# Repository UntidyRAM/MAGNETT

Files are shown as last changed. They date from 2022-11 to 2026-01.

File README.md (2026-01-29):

# MAGNETT 🧲
<b>M</b>agnetometer<br/>
<b>A</b>ugmentation<br/>
<b>G</b>adget for<br/>
<b>N</b>etwork<br/>
<b>E</b>nabled<br/>
<b>T</b>elemetry<br/>
<b>T</b>ransmission<br/>
<br/>

<p align="justify">
MAGNETT is a proof of concept device (or gadget) that allows one to retrieve measurements taken from a G-856AX (manufactured by Geometrics, Inc) over a WiFi connection. It has the ability to save a GPS position for each measurement taken by the G-856AX. It also displays the retrieved data in a table and graph on the web server.  
</p>

<p align="justify">
Our device makes use of an ESP32 and a GPS (amongst other less notable components) to realise the features mentioned above. 
</p>

This project forms part of our fourth year investigating course, for electrical engineering, at the University of the Witwatersrand, Johannesburg. 

By Huan Lei & Nicholas Warrener 

# Images
## Device
<p align="justify">
A top view image of our device can be seen below. Our device uses a 5000mAh LiPo battery. 
</p>
<br/>

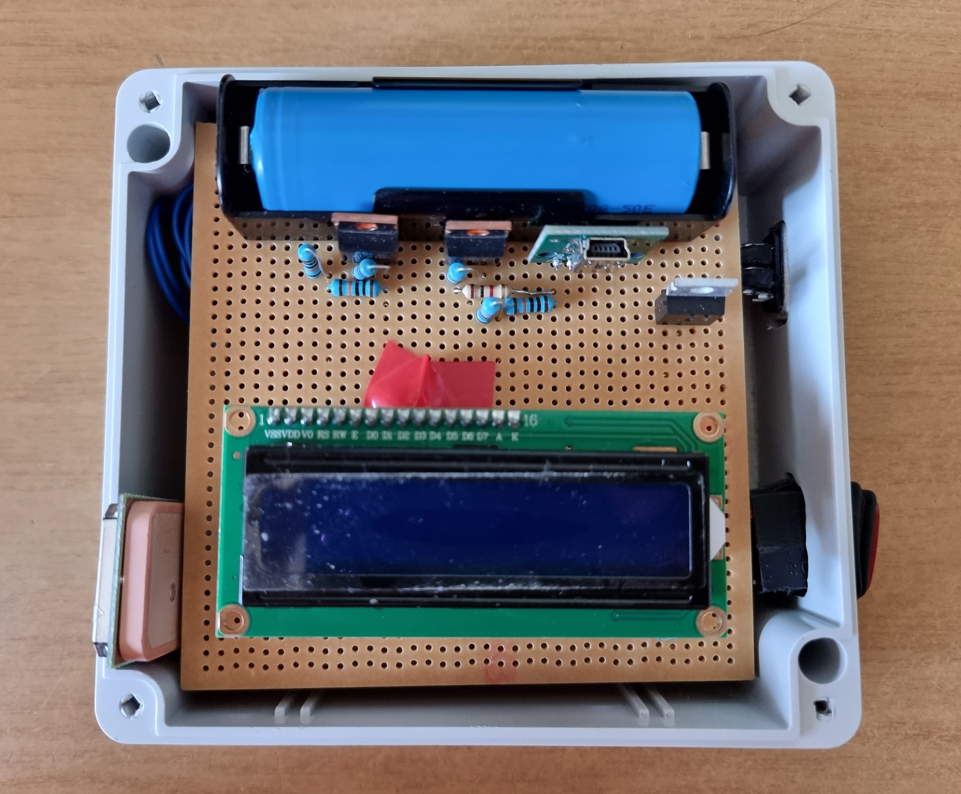
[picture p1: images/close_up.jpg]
An image showing the top view of our device. A battery, USB port, two MOSFETs, a display, and the GPS antenna can be seen. Top view of MAGNETT.


<p align="justify">
Our device and it's custom connector can be seen inside of the carrying case for a G-856AX. 
</p>
<br/>

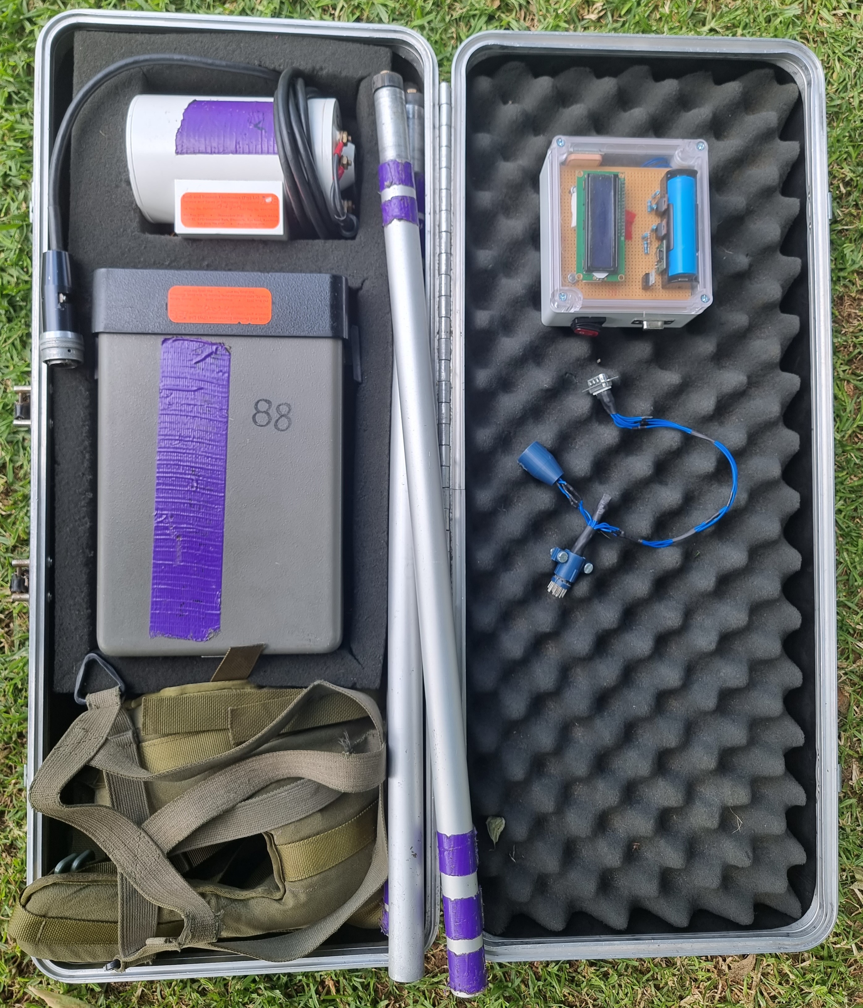
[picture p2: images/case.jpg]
An image showing our device sitting inside the carrying case for a Geometrics G-856AX proton precession magnetometer. The magnetometer's console and sensor can be seen as well as the poles used to hold up the sensor. MAGNETT with a G-856AX.


## Website 
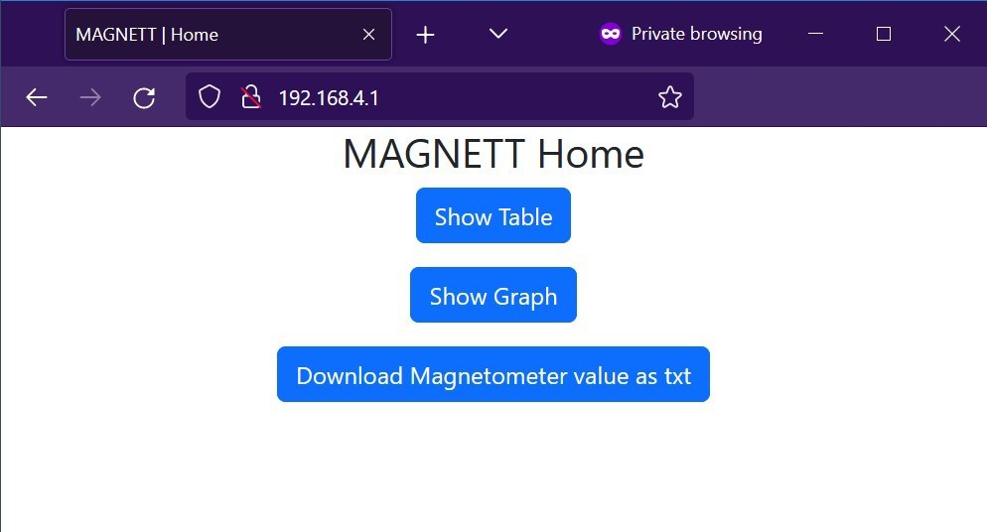
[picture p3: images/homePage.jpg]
Our device's homepage displaying three buttons: Table, Graph and Download data. MAGNETT home page.


<p align="justify">
The data in the next three images was taken from a G-856AX. The GPS data corresponding to each magnetic field reading was taken using MAGNETT's built-in NEO-6M GPS. The GPS data has been censored for privacy reasons. 
</p>
<br/>

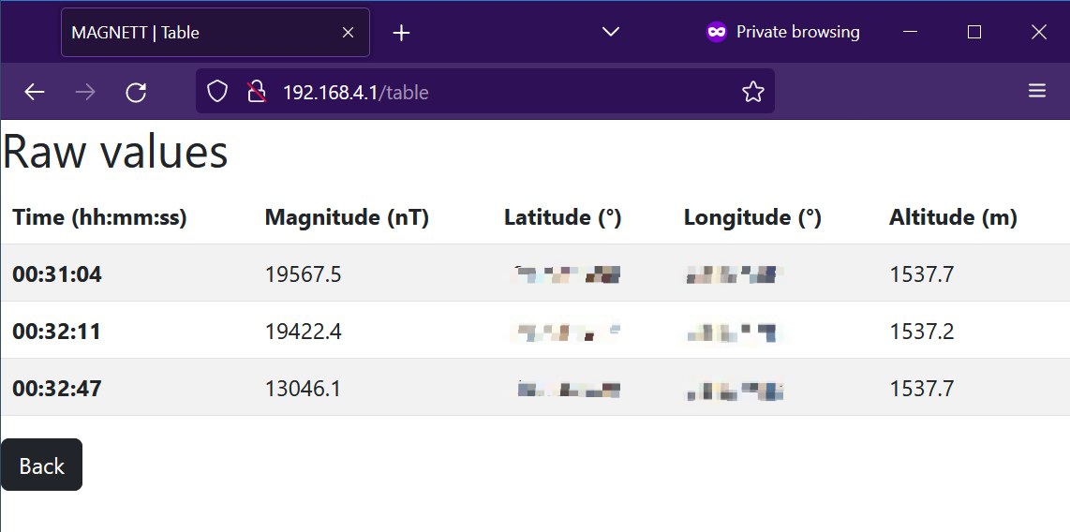
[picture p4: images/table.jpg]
A webpage displaying a table with three rows of data. MAGNETT table page.


<br/>

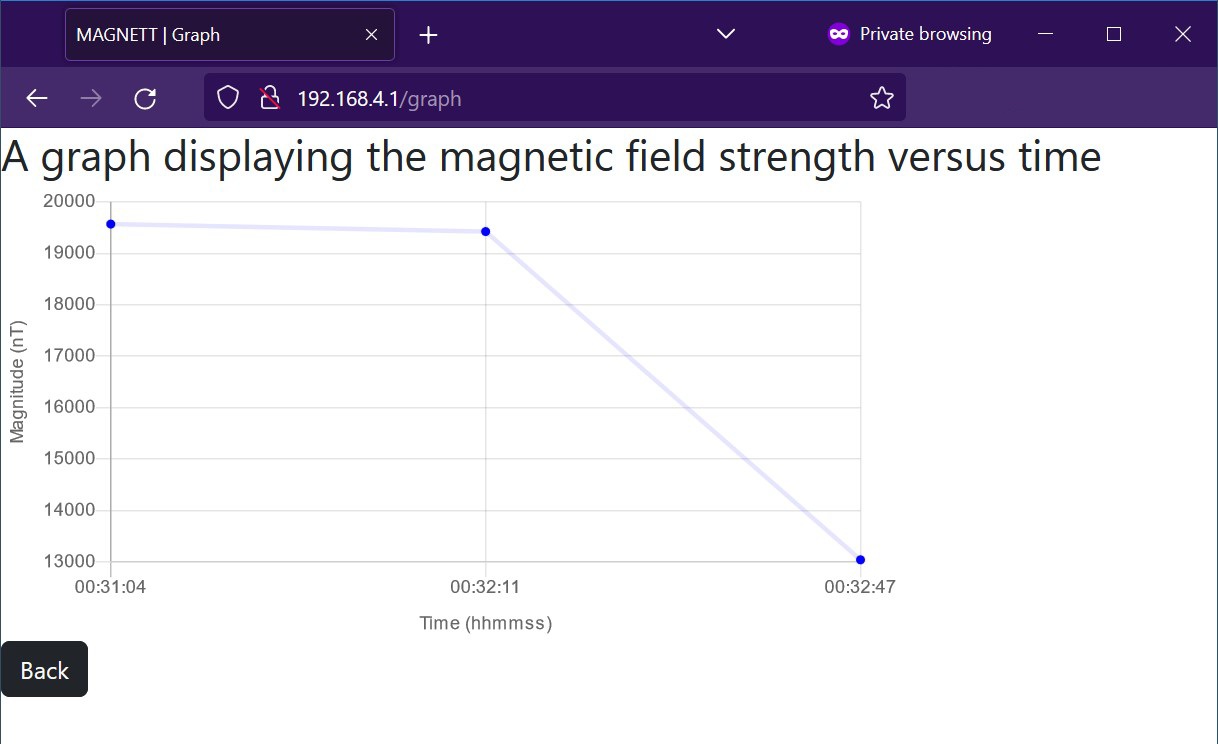
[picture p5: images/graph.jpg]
A line graph displaying a plot of the magnetic field strength versus time. MAGNETT graph page.


<br/>

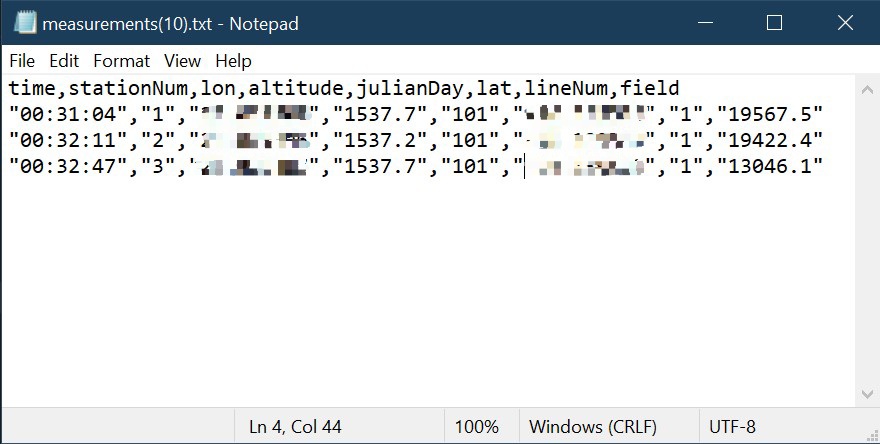
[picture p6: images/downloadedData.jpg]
A screenshot of a text document containing data downloaded from our device. MAGNETT downloaded data.


# Dependencies 
## LCD
<p align="justify">
Our project uses a generic 1609 LCD with an I2C 'backpack' to reduce the number of wires needed for communication. We used the 
<a href="https://github.com/dhylands/python_lcd">python_LCD</a> library to configure the LCD and display text. Specifically, <code>machine_i2c_lcd.py</code> and <code>lcd_api.py</code> are used from this library.
</p>

## GPS
<p align="justify">
We used the <code>as_GPS.py</code> driver from the <a href="https://github.com/peterhinch/micropython-async">micropython-async</a> library to asynchronously parse the NMEA sentences from the GPS. Just make sure to use V2 and not V3 as the newer version contains functions not supported by the version of micropython-async running on TinyWeb.
</p>

## Webserver
[Bootstrap](https://github.com/twbs/bootstrap/tree/v5.2.2/site/content/docs/5.2)- We used the latest release at the time of writing (V5.2.2) <br/>
[Chart.js](https://www.chartjs.org/docs/2.9.4/) - We used an older version (V2.9.4) of this library because we ran into issues running the latest version<br/>
[TinyWeb](https://github.com/belyalov/tinyweb) - The latest release (V1.3.5) is from 2020 which means we had to use an older version of the as_GPS library.

# Acknowledgements
<p align="justify">
We would like to thank Prof K. Nixon for supervising our project and providing us with valuable feedback at the review meetings. We would also like to thank Prof S. Webb of the Geoscience Department for providing us with the necessary hardware as well as giving us valuable feedback and information which helped us contextualize the design. 
</p>

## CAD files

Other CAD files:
models/female/Female Adapter.ipt
models/female/Inner Part of Female.ipt
models/male/Inner Part of Male.ipt
models/male/Male Adapter.ipt

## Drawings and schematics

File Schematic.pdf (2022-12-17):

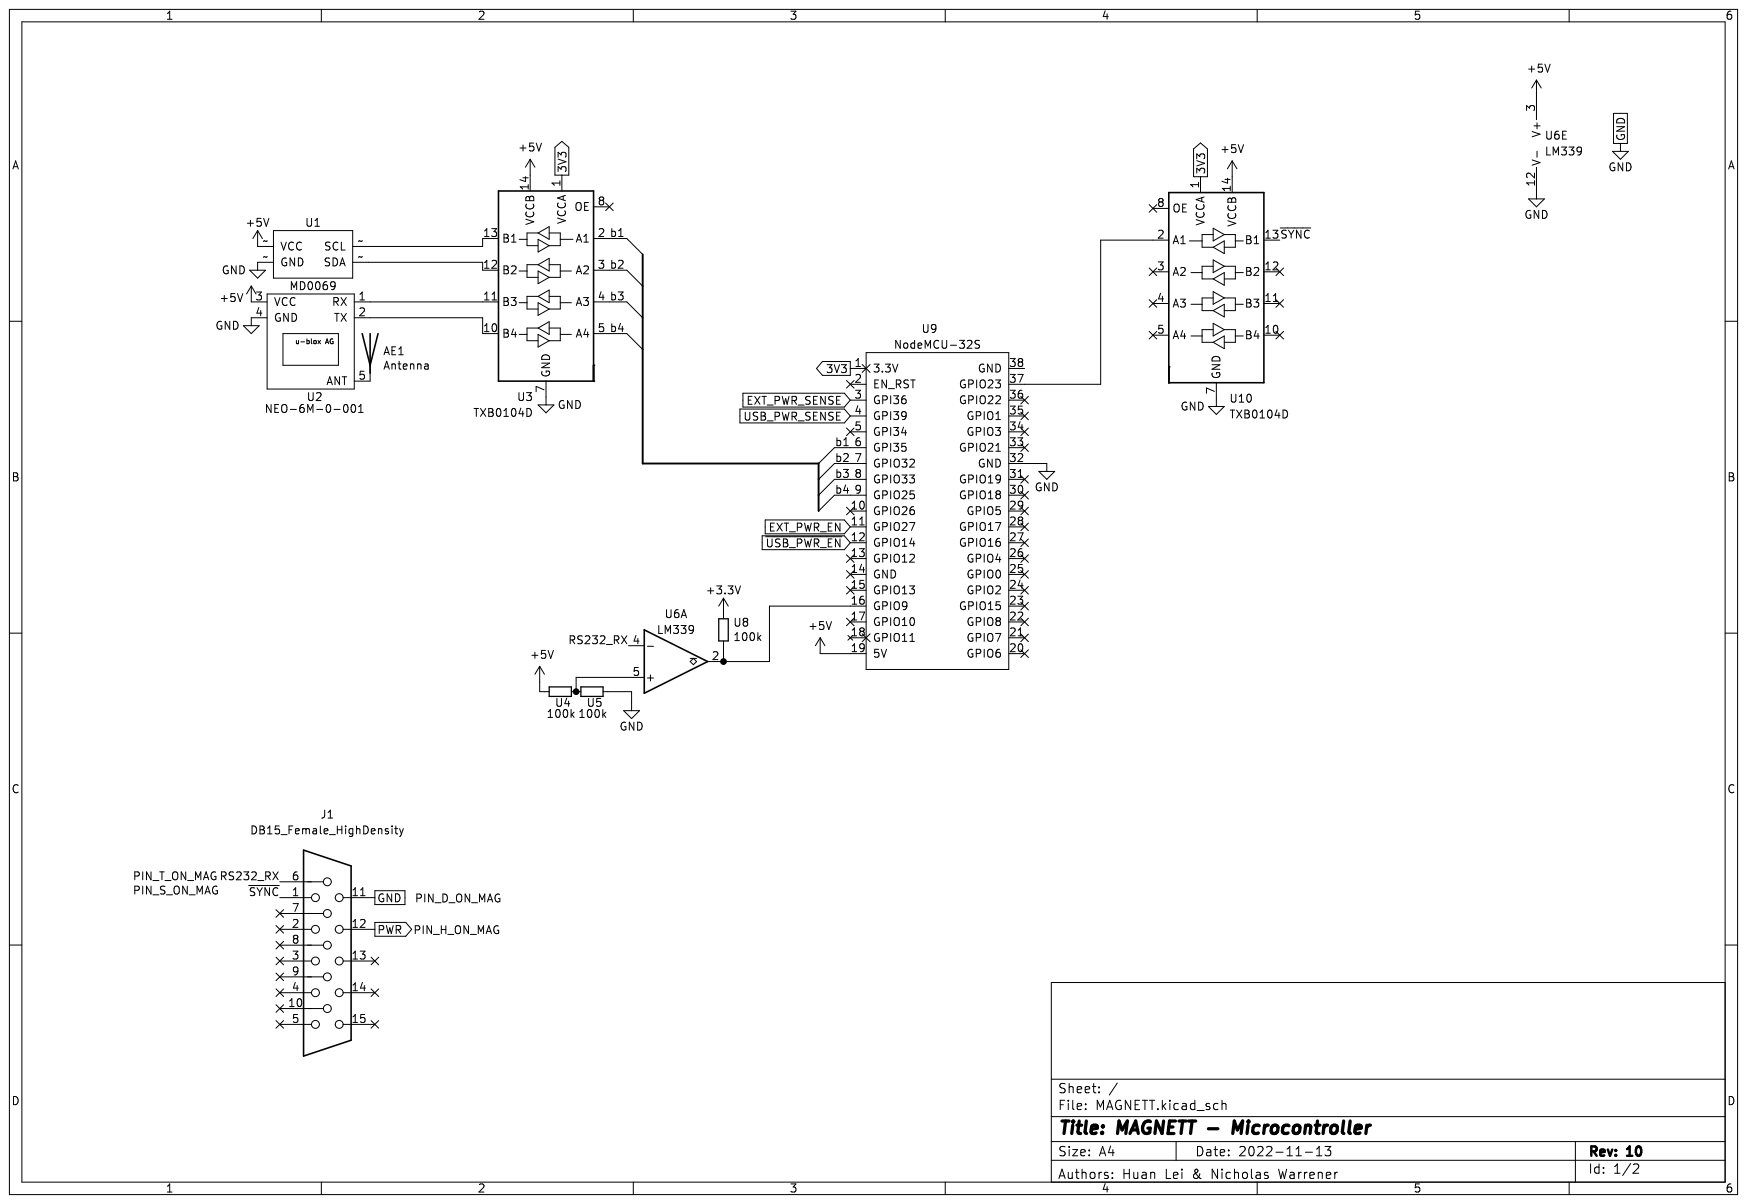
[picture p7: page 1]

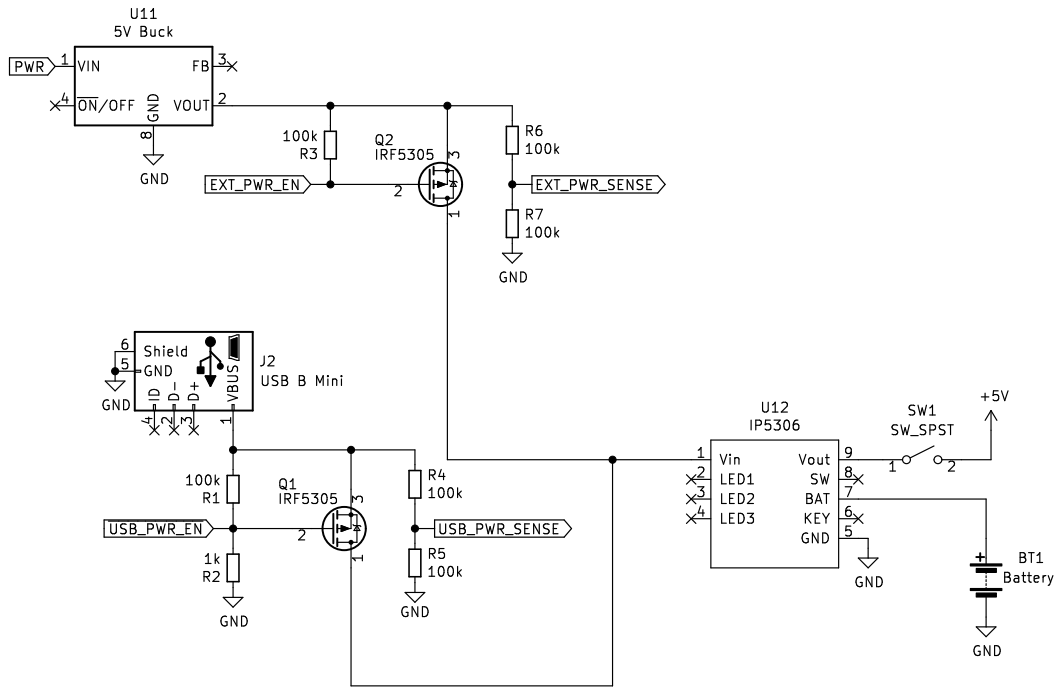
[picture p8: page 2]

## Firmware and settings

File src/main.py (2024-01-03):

# Copyright (c) 2022 Huan Lei and Nicholas Warrener 
# Released under the MIT License (MIT) - see LICENSE file

import tinyweb
import network
import time
import json
import machine
import uasyncio as asyncio

from machine import Pin, I2C, UART
from lcd_api import LcdApi
from machine_i2c_lcd import I2cLcd
from time import sleep
from AS_GPS import AS_GPS
from math import floor, modf

# LCD
I2C_ADDR = 0x27
totalRows = 2
totalColumns = 16

i2c = I2C(scl=Pin(21), sda=Pin(22), freq=10000)
lcd_obj = I2cLcd(i2c, I2C_ADDR, totalRows, totalColumns)
lcd_obj.putstr("Waiting for GPS")

# Control the MOSFETs for power selection.
# Be careful not to turn both of them on if you have two supplies connected
ext_pwr_status = Pin(19, Pin.IN)
ext_pwr_ctrl = Pin(18, Pin.OUT)
ext_pwr_ctrl.on() # Turn off external power.

usb_pwr_stats = Pin(4, Pin.IN)
usb_pwr_ctrl = Pin(5, Pin.OUT)
usb_pwr_ctrl.off() # Turn on USB power for charging.

# Globals
rs232DictArr = []
gpsDictArr = []

# Magnetometer serial
magSerial = UART(1, 9600, bits=7, parity=None, stop=2, rx=16, tx=10)

# We implement a falling edge detector in software instead of using a hardware interrupt for two reasons.
# Firstly, the time savings between asynchronously polling the pin and using a hardware interrupt is negligible.
# Secondly, introducing an interrupt into asynchronous code increases the complexity of the code.
magSyncPin = Pin(23, mode=Pin.IN)
pin_state = magSyncPin.value()
last_pin_state = pin_state

# GPS serial
gpsSerial = UART(2, baudrate=9600, bits=8, parity=None, stop=1, tx=25, rx=33) 
sreader = asyncio.StreamReader(gpsSerial)
gps = AS_GPS(sreader)
isGPSReady = False

# Create web server application
app = tinyweb.webserver()

async def gpsRecv():
    while True:
        global isGPSReady
        if isGPSReady == False:
            await gps.data_received(position=True, altitude=True)
            lcd_obj.clear()
            lcd_obj.putstr("GPS ready\nSurvey can begin")
            isGPSReady = True
            await asyncio.sleep_ms(100)
        else:
            while True:
                pin_state = magSyncPin.value()
                if not pin_state and last_pin_state:
                    await gps.data_received(position=True, altitude=True)
                    lcd_obj.clear()
                    lcd_obj.putstr("lat:" + gps.latitude_string(coord_format=4) + "\nlon:" + gps.longitude_string(coord_format=4))
                    global gpsDictArr
                    gpsDictArr.append({"lat": gps.latitude_string(coord_format=4), "lon": gps.longitude_string(coord_format=4), "altitude": str(gps.altitude)})
                    await asyncio.sleep_ms(100)

                last_pin_state = pin_state
                await asyncio.sleep_ms(10)

async def rs232Recv(uart):
    reader = asyncio.StreamReader(uart)
    while True:
        message = await reader.readline()
        await asyncio.sleep_ms(100)
        message = message.decode("ASCII")

        # Using the info in the manual, we can split up the output from the magnetometer.
        lineNum = message[1:4]
        julianDay = message[5:8]
        time = message[9:15]
        stationNum = message[16:20]
        field = message[21:27]

        # Format the time so it changes from hhmmss to hh:mm:ss.
        time = str(time[:2]) + ":" + str(time[2:4]) + ":" + str(time[4:6])

        # EDIT: The following commented out code is not correcting a bug! The '?' is intentional and indicates that the measurement was made in a high
        #       gradient.
        # Replace any question marks with zeros. This happens because of a bug in the G-856AX's serial code.
        # if '?' in field:
        #    field = field.replace('?', '0')

        # Format the field reading to have its decimal point. A raw value is 517643 which is formatted to 51764.3
        field = field[:len(field) - 1] + "." + field[len(field) - 1:]
        rs232DictArr.append({"lineNum": str(lineNum), "julianDay": str(julianDay), "time": str(time), "stationNum": str(stationNum), "field": str(field)})

        await asyncio.sleep_ms(100)


# Landing page
@app.route('/')
async def index(request, response):
    global rs232DictArr
    global gpsDictArr
    
    # Start HTTP response with content-type text/html
    await response.start_html()

    vals = ""
    # This if statement should just check that each magnetometer reading has a corresponding gps reading.
    if len(rs232DictArr) != 0 and len(gpsDictArr) != 0 and len(rs232DictArr) == len(gpsDictArr):
        #vals = "lineNum, julianDay, time, stationNum, field, lat, lon, altitude\b"
        for x in range(len(rs232DictArr)):
            rs232DictArr[x].update(gpsDictArr[x])

        vals = json.dumps(rs232DictArr)
    else:
        # Our device is just being used to pull readings from the magnetometer. It wasn't used to save GPS values for each reading.
        if len(rs232DictArr) != 0 and len(gpsDictArr) == 0:
            #vals = "lineNum, julianDay, time, stationNum, field\n"
            for i in range(len(rs232DictArr)):
                vals += json.dumps(rs232DictArr[i]) 

    strHtml = """<!DOCTYPE html>
    <html>
    <head>
         <title>MAGNETT | Home</title>
        <meta name="viewport" content="width=device-width, initial-scale=1">
        <link href="/css" rel="stylesheet">
        <style>
            html {
                font-family: Arial;
                display: inline-block;
                margin: 0px auto;
                text-align: center;
            }

            .button {
                background-color: #000000;
                border: none;
                color: white;
                padding: 16px 40px;
                text-align: center;
                text-decoration: none;
                display: inline-block;
                font-size: 16px;
                margin: 4px 2px;
                cursor: pointer;
                border-radius: 25px;
            }
        </style>
    </head>

    <script>
    function download()
    {
        const json3 = {"count": """+str(len(rs232DictArr))+""", "items":""" + str(vals) + """}
        const items = json3.items
        const replacer = (key, value) => value === null ? '' : value // specify how you want to handle null values here
        const header = Object.keys(items[0])
        const csv = [
            header.join(','), // header row first
            ...items.map(row => header.map(fieldName => JSON.stringify(row[fieldName], replacer)).join(','))
        ].join("\\r\\n")

        var link = document.createElement('a');
        link.setAttribute('href', 'data:text;charset=utf-8,' + encodeURIComponent(csv));
        link.setAttribute('download', 'measurements.txt');
        link.style.visibility = 'hidden';
        document.body.appendChild(link);
        link.click();
        document.body.removeChild(link);
    }
    </script>

    <body>
        <h2>MAGNETT Home</h2>
        <p>
            <a href=\"table\"><button class="btn btn-primary">Show Table</button></a>
        </p>
        <p>
            <a href=\"graph\"><button class="btn btn-primary">Show Graph</button></a>
        </p>
        <p>
        
        <button class="btn btn-primary" onclick="download()">Download Magnetometer value as txt</button> 
        <a id="readings" style="display:none"></a>

        </p>
    </body>
    </html>
    """

    # Send actual HTML page
    await response.send(strHtml)

@app.route('/about')
async def index(request, response):
    # Start HTTP response with content-type text/html
    await response.start_html()

    strHtml = """
    <!DOCTYPE html>
    <html>
    <head>
         <title>MAGNETT | About</title>
        <meta name="viewport" content="width=device-width, initial-scale=1">
        <link href="/css" rel="stylesheet">
    </head>

    <body>
        <h2>MAGNETT About</h2>
        <p>
            This device was made for the Geoscience Department by Huan Lei and Nicholas Warrener for their final year investigation project. The code and design files can be found on GitHub by searching for the 'MAGNETT' repo maintained by Ray-R4y and UntidyRAM.
        </p>
    </body>
    </html>
    """
    
    # Send actual HTML page
    await response.send(strHtml)

@app.route('/js')
async def getChartLib(req, res):
    await res.send_file('/Chart.js')

@app.route('/css')
async def getChartLib(req, res):
    await res.send_file('/bootstrap.min.css')

#this is  where the chart.js and the new page will be using the /table with button above
@app.route('/table')
async def table(request, response):
    # Start HTTP response with content-type text/html
    await response.start_html()

    if len(gpsDictArr) != 0:
        await response.send('<!DOCTYPE html><html><head><title>MAGNETT | Table</title><link href="/css" rel="stylesheet"></head><body><h1>Raw values</h1>'
                            '<table class="table table-striped">'
                            '<thead>'
                                '<tr>'
                                    '<th scope="col">Time (hh:mm:ss)</th>'
                                    '<th scope="col">Magnitude (nT)</th>'
                                    '<th scope="col">Latitude (&deg;)</th>'
                                    '<th scope="col">Longitude (&deg;)</th>'
                                    '<th scope="col">Altitude (m)</th>'
                                    '</tr>'
                            '</thead>'
                            '<tbody>')

        # The table value here is a bit tricky, but we can pull it off from list, the format underneath here
        # so if we want the x and y value we put in change  it to format(x,y)

        cntr = 0

        for x in rs232DictArr:
            jsonData = json.dumps(x)
            data = json.loads(jsonData)

            tempJsonData = json.dumps(gpsDictArr[cntr])
            tempData = json.loads(tempJsonData)

            await response.send('<tr><th scope="row">' + data['time'] + '</th><td>' + data['field'] + '</td><td>' + tempData['lat'] + '</td><td>' + tempData['lon'] + '</td><td>' + tempData['altitude'] + '</td></tr>')
            
            cntr = cntr + 1

    else:
        await response.send('<!DOCTYPE html><html><head><title>MAGNETT | Table</title><link href="/css" rel="stylesheet"></head><body><h1>Raw values</h1>'
                            '<table class="table table-striped">'
                            '<thead>'
                                '<tr>'
                                    '<th scope="col">Time (hh:mm:ss)</th>'
                                    '<th scope="col">Magnitude (nT)</th>'
                                    '</tr>'
                            '</thead>'
                            '<tbody>')

        # The table value here is a bit tricky, but we can pull it off from list, the format underneath here
        # so if we want the x and y value we put in change  it to format(x,y)

        for x in rs232DictArr:
            jsonData = json.dumps(x)
            data = json.loads(jsonData)

            await response.send('<tr><th scope="row">' + data['time'] + '</th><td>' + data['field'] + '</td></tr>') 

    await response.send('</tbody></table>'
                        """<button type="button" class="btn btn-dark" onclick="history.go(-1)">Back</button></html>""")
    
@app.route('/graph')
async def graph(request, response):
    # Start HTTP response with content-type text/html
    await response.start_html()
  
    xValue = ""
    yValue = ""
    #try getting real values
    for x in rs232DictArr:
        jsonData = json.dumps(x)
        data = json.loads(jsonData)
        xValue = xValue + "'"+(data['time']) + "',"
        yValue = yValue + "'"+(data['field']) + "',"   
    xValue = xValue[:-1]
    yValue = yValue[:-1]
    await response.send("""
    <!DOCTYPE html>
    <html>
    <head>
        <title>MAGNETT | Graph</title>
        <link href="/css" rel="stylesheet">
    </head>
    <script type="application/javascript" src="/js"></script>

    <body>
        <h2>A graph displaying the magnetic field strength versus time</h2>
        <canvas id="FieldStrengthTimeGraph" style="width:100%;max-width:600px"></canvas>

        <script>
            let xValues = [""" + xValue +"""];
            let yValues = [""" + yValue +"""];

            new Chart("FieldStrengthTimeGraph", {
                type: "line",
                data: {
                    labels: xValues,
                    datasets: [{
                        fill: false,
                        lineTension: 0,
                        backgroundColor: "rgba(0,0,255,1.0)",
                        borderColor: "rgba(0,0,255,0.1)",
                        data: yValues
                    }]
                },
                options: {
                    legend: { display: false },
                    scales: {
                        yAxes: [{
                            scaleLabel: {
                                display: true,
                                labelString: 'Magnitude (nT)'
                            }
                        }],
                        xAxes: [{
                            scaleLabel: {
                                display: true,
                                labelString: 'Time (hhmmss)'
                            }
                        }],
                    }
                }
            });
        </script>
        <button type="button" class="btn btn-dark" onclick="history.go(-1)">
            Back
        </button>
    </body>
    </html>""")
    
          
async def main():
    sta_if = network.WLAN(network.AP_IF)
    sta_if.active(True)
    sta_if.config(essid='MAGNETT', password='123456789')

    while sta_if.active() == False:
        pass

    # Loop_forever=True would turn this function into a blocking function which would stop
    # our code below it from running.
    app.run(host='0.0.0.0', port=80, loop_forever=False)

    loop = asyncio.get_event_loop()
    loop.create_task(rs232Recv(magSerial))
    loop.create_task(gpsRecv())

loop = asyncio.get_event_loop()
loop.create_task(main())
loop.run_forever()

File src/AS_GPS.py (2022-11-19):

# as_GPS.py Asynchronous device driver for GPS devices using a UART.
# Sentence parsing based on MicropyGPS by Michael Calvin McCoy
# https://github.com/inmcm/micropyGPS
# http://www.gpsinformation.org/dale/nmea.htm
# Docstrings removed because of question marks over their use in resource
# constrained systems e.g. https://github.com/micropython/micropython/pull/3748

# Copyright (c) 2018-2020 Peter Hinch
# Released under the MIT License (MIT) - see LICENSE file

# astests.py runs under CPython but not MicroPython because mktime is missing
# from Unix build of utime

try:
    import uasyncio as asyncio
except ImportError:
    import asyncio

try:
    from micropython import const
except ImportError:
    const = lambda x : x

from math import modf

# Float conversion tolerant of empty field
# gfloat = lambda x : float(x) if x else 0.0

# Angle formats
DD = const(1)
DMS = const(2)
DM = const(3)
KML = const(4)
# Speed units
KPH = const(10)
MPH = const(11)
KNOT = const(12)
# Date formats
MDY = const(20)
DMY = const(21)
LONG = const(22)

# Sentence types
RMC = const(1)
GLL = const(2)
VTG = const(4)
GGA = const(8)
GSA = const(16)
GSV = const(32)
# Messages carrying data
POSITION = const(RMC | GLL | GGA)
ALTITUDE = const(GGA)
DATE = const(RMC)
COURSE = const(RMC | VTG)


class AS_GPS(object):
    # Can omit time consuming checks: CRC 6ms Bad char and line length 9ms
    FULL_CHECK = True
    _SENTENCE_LIMIT = 76  # Max sentence length (based on GGA sentence)
    _NO_FIX = 1

    # Return day of week from date. Pyboard RTC format: 1-7 for Monday through Sunday.
    # https://stackoverflow.com/questions/9847213/how-do-i-get-the-day-of-week-given-a-date-in-python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
    # Adapted for Python 3 and Pyboard RTC format.
    @staticmethod
    def _week_day(year, month, day, offset = [0, 31, 59, 90, 120, 151, 181, 212, 243, 273, 304, 334]):
        aux = year - 1700 - (1 if month <= 2 else 0)
        # day_of_week for 1700/1/1 = 5, Friday
        day_of_week  = 5
        # partial sum of days betweem current date and 1700/1/1
        day_of_week += (aux + (1 if month <= 2 else 0)) * 365
        # leap year correction
        day_of_week += aux // 4 - aux // 100 + (aux + 100) // 400
        # sum monthly and day offsets
        day_of_week += offset[month - 1] + (day - 1)
        day_of_week %= 7
        day_of_week = day_of_week if day_of_week else 7
        return day_of_week

    # 8-bit xor of characters between "$" and "*". Takes 6ms on Pyboard!
    @staticmethod
    def _crc_check(res, ascii_crc):
        try:
            crc = int(ascii_crc, 16)
        except ValueError:
            return False
        x = 1
        crc_xor = 0
        while res[x] != '*':
            crc_xor ^= ord(res[x])
            x += 1
        return crc_xor == crc

    def __init__(self, sreader, local_offset=0, fix_cb=lambda *_ : None, cb_mask=RMC, fix_cb_args=()):
        self._sreader = sreader  # If None testing: update is called with simulated data
        self._fix_cb = fix_cb
        self.cb_mask = cb_mask
        self._fix_cb_args = fix_cb_args
        self.battery = False  # Assume no backup battery

        # CPython compatibility. Import utime or time for fix time handling.
        try:
            import utime
            self._get_time = utime.ticks_ms
            self._time_diff = utime.ticks_diff
            self._localtime = utime.localtime
            self._mktime = utime.mktime
        except ImportError:
            # Otherwise default to time module for non-embedded implementations
            # Should still support millisecond resolution.
            import time
            self._get_time = time.time
            self._time_diff = lambda start, end: 1000 * (start - end)
            self._localtime = time.localtime
            self._mktime = time.mktime

        # Key: currently supported NMEA sentences. Value: parse method.
        self.supported_sentences = {'RMC': self._gprmc, 
                                    'GGA': self._gpgga,
                                    'VTG': self._gpvtg,
                                    'GSA': self._gpgsa,
                                    'GSV': self._gpgsv,
                                    'GLL': self._gpgll,
                                    }

        #####################
        # Object Status Flags
        self._fix_time = None

        #####################
        # Sentence Statistics
        self.crc_fails = 0
        self.clean_sentences = 0
        self.parsed_sentences = 0
        self.unsupported_sentences = 0

        #####################
        # Data From Sentences
        # Time. http://www.gpsinformation.org/dale/nmea.htm indicates seconds
        # is an integer. However hardware returns a float, but the fractional
        # part is always zero. So treat seconds value as an integer. For
        # precise timing use PPS signal and as_tGPS library.
        self.local_offset = local_offset  # hrs
        self.epoch_time = 0  # Integer secs since epoch (Y2K under MicroPython)
        # Add ms if supplied by device. Only used by timing drivers.
        self.msecs = 0

        # Position/Motion
        self._latitude = [0, 0.0, 'N']  # (°, mins, N/S)
        self._longitude = [0, 0.0, 'W']  # (°, mins, E/W)
        self._speed = 0.0  # Knot
        self.course = 0.0  # ° clockwise from N
        self.altitude = 0.0  # Metres
        self.geoid_height = 0.0  # Metres
        self.magvar = 0.0  # Magnetic variation (°, -ve == west)

        # State variables
        self._last_sv_sentence = 0  # for GSV parsing
        self._total_sv_sentences = 0
        self._satellite_data = dict()  # for get_satellite_data()
        self._update_ms = 1000  # Update rate for timing drivers. Default 1 sec.

        # GPS Info
        self.satellites_in_view = 0
        self.satellites_in_use = 0
        self.satellites_used = []
        self.hdop = 0.0
        self.pdop = 0.0
        self.vdop = 0.0

        # Received status
        self._valid = 0  # Bitfield of received sentences
        if sreader is not None:  # Running with UART data
            loop = asyncio.get_event_loop()
            loop.create_task(self._run(loop))

    ##########################################
    # Data Stream Handler Functions
    ##########################################

    async def _run(self, loop):
        while True:
            res = await self._sreader.readline()
            try:
                res = res.decode('utf8')
            except UnicodeError:  # Garbage: can happen e.g. on baudrate change
                continue
            loop.create_task(self._update(res))
            await asyncio.sleep(0)  # Ensure task runs and res is copied
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

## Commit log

2022-11-14 Add files via upload
    Added the custom connecter models
    [Female adaptor.ipt, inner Part of Adaptor.ipt, inner Part of male.ipt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]
2022-11-19 Create main.py
    Initial version for proof of concept. Still need to refactor and squash some bugs.
    [main.py]
2022-11-19 Update README.md
    Added credit for the drivers used in this project.
2022-11-20 Update main.py
    Fixed an issue with downloading the data.
    [main.py]
2022-12-17 Add files via upload
    Added schematics.
